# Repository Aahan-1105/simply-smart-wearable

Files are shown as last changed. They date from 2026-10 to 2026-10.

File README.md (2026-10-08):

# simply-wearable

## Overview
simply_wearable was created for the Half-Life program by hackclub for week 1: PCB Week.

I recently got a G-SHOCK and love it, but miss step counting from my old watch, so I decided to create a simple wearable with step tracking and a few buttons. I also decided to add a screen as a simple way to make it cooler without significant complexity. 

## Features
- BLE to phone
- Step counting
- oled screen with images and info
- 2 buttons for control
- Remote shutter for group photos
- Battery voltage monitoring
- 110maH battery with usb-c charging
- Built for under $30 USD

## Photos



Finished PCB Excluding Ground Fill



Finished Schematic

Renders of the PCB and CAD will be added as completed!

## BOM
|Purchase Status|Part |Qty|Price (USD)|Total |Link |Shipping/Tax|Notes |
|---|---|---|---|---|---|---|---|
| |301230 Battery |1  |$10.05 |$10.05|https://www.aliexpress.com/item/1005005348368664.html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!| |Powers the wearable |
| |Passive components|1  |$4.92 |$4.92 |https://www.aliexpress.com/item/1005012364450156.html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! | |Capacitor and buttons |
| |0.91" oled screen |1  |$3.58 |$3.58 |https://www.aliexpress.com/item/1005012327947468.html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!| |displaying info and cat gifs |
| |GY-BMI160 |1  |$1.62 |$1.62 |https://www.aliexpress.com/item/1005012327947468.html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!| |step counting! |
| |PCB |1  |$10.85 |$10.85|https://github.com/Aahan-1105/simply-wearable/blob/main/Images/JLCPCB_Cart.png | |Hold components and connect them|
| | | | | | | | |
| | | | | | | | |
| |TOTAL (USD) | |$31.02 |$0.00 | | | |
| |TOTAL (CAD) | |$43.20 |$0.00 | | | |

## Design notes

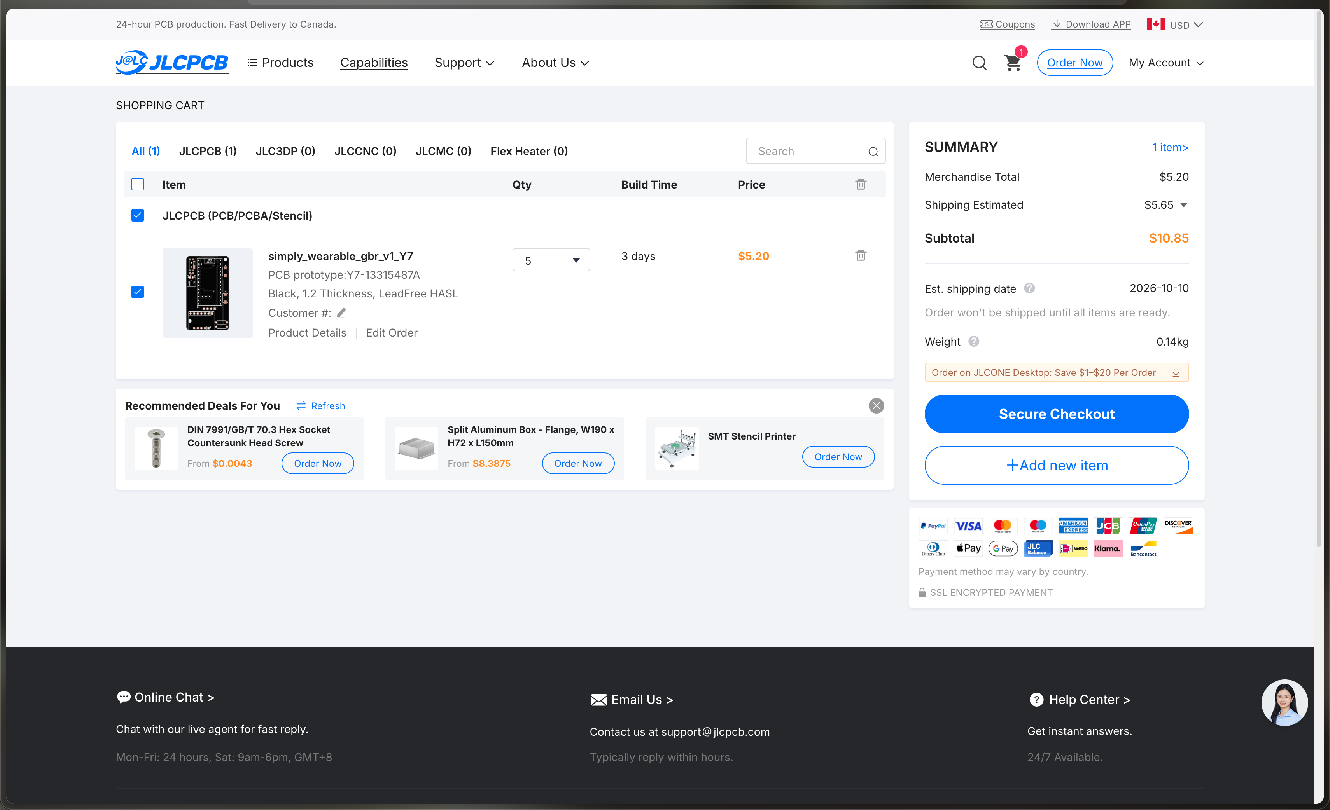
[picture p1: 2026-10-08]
Images/JLCPCB_Cart.png

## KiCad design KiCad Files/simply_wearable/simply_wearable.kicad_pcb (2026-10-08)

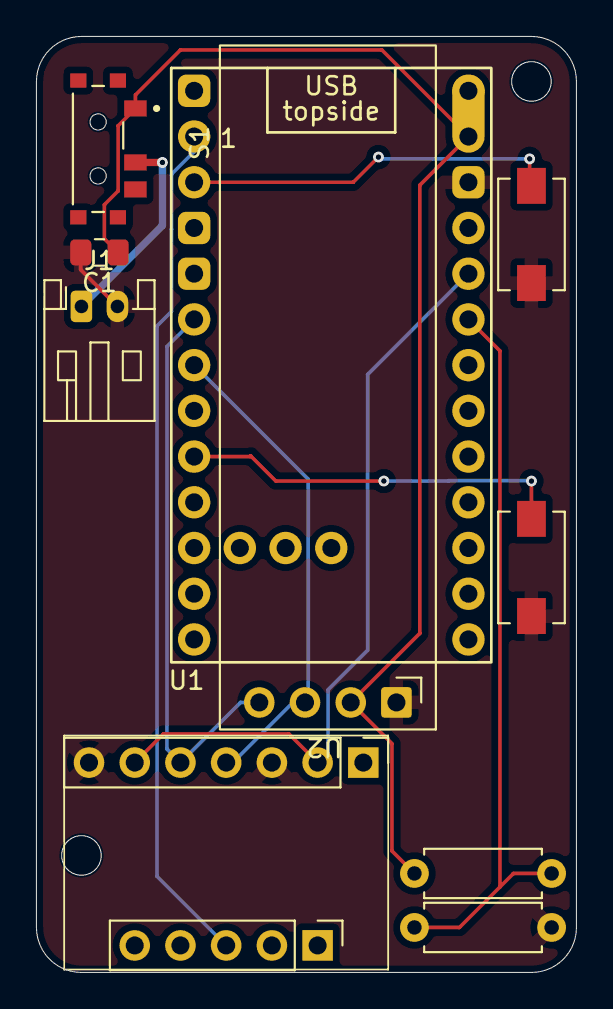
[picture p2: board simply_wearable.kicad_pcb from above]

Board: 2 copper layers, 30.0 x 52.0 mm, 11 parts (0 on the bottom side), 10 nets.

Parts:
C1: C; C_0805_2012Metric_Pad1.18x1.45mm_HandSolder
J1: Conn_01x02_Socket; JST_PH_S2B-PH-K_1x02_P2.00mm_Horizontal
J3: Conn_01x07_Socket; PinHeader_1x07_P2.54mm_Vertical
J4: Conn_01x05_Socket; PinHeader_1x05_P2.54mm_Vertical
R3, R4: 10K; R_Axial_DIN0207_L6.3mm_D2.5mm_P7.62mm_Horizontal
S1: MSK12C02; SW_MSK12C02
SW1, SW2: SW_Push; SW_SPST_EVQPE1
U1: nice_nano; nice_nano_AH_USBup
U2: ER_OLEDM0.91_1x-I2C

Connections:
/3v3: J3.2, J3.6, U1.16 (3V3)
/BAT+: J1.1, S1.2
/GND: C1.2, J1.2, J3.3, J3.7, R4.2, SW1.2, SW2.2, U1.14 (GND), U2.1 (GND)
/INT1: J4.3 (Pin_3_3), U1.1 (P0.06)
/Primary: SW1.1, U1.2 (P0.08)
/SCL: J3.4, U1.6 (P0.20), U2.3 (SCL)
/SDA: J3.5, U1.5 (P0.17), U2.4 (SDA)
/Secondary: SW2.1, U1.8 (P0.24)
/VCC: C1.1, R3.1, S1.1, U1.13 (BAT+), U1.29 (BAT+), U2.2 (VCC)
unnamed: R3.2, R4.1, U1.17 (P0.31-LF)

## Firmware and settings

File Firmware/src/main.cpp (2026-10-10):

#include <Adafruit_TinyUSB.h>
#include <Arduino.h>
#include "display.h"
#include "step_counter.h"
#include "button.h"
#include "storage.h"

#define DISPLAY_TIMEOUT_MS  5000         // 5 seconds auto-sleep
#define SAVE_INTERVAL_MS    (15 * 60 * 1000) // 15 minutes between flash writes
#define SAVE_STEP_DELTA     100          // Must have at least 100 new steps to trigger save

DisplayManager display;
StepCounter stepCounter;
ButtonDriver userButton;
StorageManager storage;

volatile bool stepDetected = false;
volatile bool buttonPressed = false;

volatile uint16_t stepPulseCount = 0;
volatile uint32_t lastButtonInterruptTime = 0;

bool displayIsOn = true;
uint32_t displayWakeTimestamp = 0;

uint32_t persistentSteps = 0;     // Steps loaded from flash at boot
uint32_t lastSavedTotalSteps = 0; // Total steps at the last flash write
uint32_t lastSaveTimestamp = 0;   // millis() timestamp of last flash write

void handleStepISR() {
    stepPulseCount++;
    if (stepPulseCount >= STEP_WAKE_THRESHOLD) {
        stepPulseCount = 0;
        stepDetected = true;
    }
}

void handleButtonISR() {
    uint32_t currentTime = millis();
    if (currentTime - lastButtonInterruptTime > DEBOUNCE_DELAY_MS) {
        buttonPressed = true;
        lastButtonInterruptTime = currentTime;
    }
}

void wakeDisplay() {
    if (!displayIsOn) {
        display.turnOn();
        displayIsOn = true;
    }
    uint32_t totalSteps = persistentSteps + stepCounter.getSteps();
    display.renderStepCount(totalSteps);
    displayWakeTimestamp = millis();
}

void setup() {
    Serial.begin(115200);
    delay(500);

    Serial.println("==================================");
    Serial.println(" Wearable Step Counter Initialized ");
    Serial.println("==================================");

    // 1. Initialize Storage & Load Saved Steps
    if (!storage.begin()) {
        Serial.println("[ERROR] LittleFS Flash Init Failed!");
    } else {
        persistentSteps = storage.loadStepCount();
        lastSavedTotalSteps = persistentSteps;
        lastSaveTimestamp = millis();
        Serial.print("[OK] Flash Storage Ready. Loaded Steps: ");
        Serial.println(persistentSteps);
    }

    // 2. Initialize Display
    if (!display.begin()) {
        Serial.println("[ERROR] SSD1306 OLED init failed!");
    } else {
        Serial.println("[OK] SSD1306 OLED Ready");
        display.showMessage("Booting...");
    }

    // 3. Initialize IMU Step Engine
    if (!stepCounter.begin()) {
        Serial.println("[ERROR] BMI160 IMU init failed!");
        display.showMessage("IMU Error!");
    } else {
        Serial.println("[OK] BMI160 Step Detector Ready");
        stepCounter.setupInterrupt(handleStepISR);
        display.showMessage("Sensor Ready!");
    }

    // 4. Initialize Button
    userButton.begin(handleButtonISR);

    delay(1000);
    wakeDisplay();
}

void loop() {
    uint32_t currentTotalSteps = persistentSteps + stepCounter.getSteps();

    // 1. Process 100-step batch event
    if (stepDetected) {
        stepDetected = false;
        Serial.print("100-Step Event Triggered! Total: ");
        Serial.println(currentTotalSteps);

        wakeDisplay();
    }

    // 2. Process manual button press
    if (buttonPressed) {
        buttonPressed = false;
        Serial.println("Button Pressed: Waking Display");

        wakeDisplay();
    }

    // 3. Auto-sleep timer evaluation & conditional periodic save
    if (displayIsOn && (millis() - displayWakeTimestamp >= DISPLAY_TIMEOUT_MS)) {
        
        // Only write to flash if 15+ mins have passed AND we have 100+ new steps
        bool timeElapsed = (millis() - lastSaveTimestamp >= SAVE_INTERVAL_MS);
        bool stepsAccumulated = ((currentTotalSteps - lastSavedTotalSteps) >= SAVE_STEP_DELTA);

        if (timeElapsed && stepsAccumulated) {
            Serial.println("Periodic Threshold Met: Writing to Flash...");
            storage.saveStepCount(currentTotalSteps);
            lastSavedTotalSteps = currentTotalSteps;
            lastSaveTimestamp = millis();
        }

        Serial.println("Display Timeout: Entering Sleep");
        display.turnOff();
        displayIsOn = false;
    }

    delay(100); 
}

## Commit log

2026-10-06 KiCad Files Added
    [Untitled.kicad_pcb, Untitled.kicad_sch]
2026-10-07 Day 2 Work (journal)
    [Untitled.kicad_pcb, Untitled.kicad_sch, simply_wearable.kicad_pcb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]
2026-10-08 PCB Completed and Production Files Added
    [simply_wearable.kicad_pcb, simply_wearable.kicad_sch]
2026-10-08 updated BOM.csv
    [BOM.csv, simply_wearable_BOM - Sheet1.csv]
2026-10-08 PCB Files updates
    [simply_wearable.kicad_pcb]
